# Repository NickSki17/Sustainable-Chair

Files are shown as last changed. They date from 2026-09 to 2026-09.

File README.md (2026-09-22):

# Interlocking Sustainable Foam-Core Chair

A full-scale chair developed around foam-core structural design, interlocking assembly, and laser-cut fabrication. The project includes concept selection, Autodesk Inventor CAD, preliminary FEA, fabrication, and a documented static prototype demonstration.

**Tools:** Autodesk Inventor, Inventor FEA, laser cutting, foam-core fabrication

## Objective and requirements

The design objective was to create a lightweight chair that satisfied the documented dimensional and manufacturing constraints while targeting a 103 kg static-load requirement.

| Requirement | Documented value |
| :--- | :--- |
| Material | 5 mm foam-core sheets |
| Sheet envelope | 457 x 610 mm |
| Target mass | Below 800 g; preferred stretch target below 400 g |
| Assembly | Interlocking slots and tabs; no external fasteners, adhesives, or tape |
| Seat height | 480-530 mm |
| Seat envelope | 410-450 mm wide and deep |
| Backrest height | 280-480 mm |
| Static load requirement | 103 kg |

The engineering report gives a **462 g CAD-predicted mass** calculated from Inventor geometry and material density. This is not a documented physical scale measurement.

## Concept development and selection

Three structural concepts were compared using a Pugh matrix across nine weighted criteria: dimensions, mass, comfort, fabrication, design effort, part count, fastening requirements, appearance, and probability of success. The multi-rib interlocking concept was selected for detailed design.

## Mechanical design and analysis

The selected design uses multi-rib foam-core construction with interlocking slot-and-tab joints. Lines-of-force analysis was used to consider load paths and likely stress-concentration regions before detailed modeling.

The [design-choice and FEA document](Sustainable%20Chair%20Design%20Choice%20and%20FEA.pdf) and [engineering report](Sustainable_Chair_Report.pdf) contain the available analysis documentation, including Autodesk Inventor FEA figures for seat and backrest loading conditions. The original FEA study files and result database are not included.

## Fabrication and physical test

The documented workflow included generating flat-pattern geometry from the CAD design, laser cutting 5 mm foam-core stock, and assembling the parts with press-fit joints without glue or mechanical fasteners.

The available [before-test documentation](Chair%20Before%20Test.pdf) and [after-test documentation](Chair%20After%20Test.pdf) show the physical prototype test evidence. The project documents a static demonstration in which the prototype supported a 103 kg load with minimal observed local damage afterward. This is a physical observation from the documented demonstration, not a load-cell measurement, structural certification, or durability test.

## Sustainability considerations and limitations

The design explores material-conscious choices through low-mass geometry, flat-pattern fabrication, reduced part count, and an interlocking assembly that avoids adhesives and external fasteners. These are design considerations, not a quantified lifecycle or environmental assessment.

The repository does not include carbon-footprint, embodied-energy, cost, lifecycle, or quantified waste-reduction calculations. It also does not include a documented physical mass measurement or durability study.

## Repository structure

```text
Sustainable-Chair/
|-- README.md
|-- .gitignore
|-- Chair After Test.pdf
|-- Chair Before Test.pdf
|-- Sustainable Chair Design Choice and FEA.pdf
|-- Sustainable Chair Ideas.pdf
|-- Sustainable_Chair_Report.pdf
`-- CAD/
    |-- sustainable_chair_assembly.iam
    |-- sustainable_chair_presentation.ipn
    `-- Parts/
        |-- backrest.ipt
        |-- inside_leg.ipt
        |-- inside_leg_2.ipt
        |-- outside_leg.ipt
        |-- seat.ipt
        |-- slats.ipt
        |-- slats_back_over.ipt
        |-- slats_back_under.ipt
        `-- slats_under.ipt
```

## Project files

- [Assembly](CAD/sustainable_chair_assembly.iam)
- [Presentation](CAD/sustainable_chair_presentation.ipn)
- [Parts directory](CAD/Parts/)
- [Engineering report](Sustainable_Chair_Report.pdf)
- [Design choice and FEA document](Sustainable%20Chair%20Design%20Choice%20and%20FEA.pdf)
- [Ideas and concept-development document](Sustainable%20Chair%20Ideas.pdf)
- [Before-test documentation](Chair%20Before%20Test.pdf)
- [After-test documentation](Chair%20After%20Test.pdf)

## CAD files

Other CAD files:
CAD/Parts/backrest.ipt
CAD/Parts/inside_leg.ipt
CAD/Parts/inside_leg_2.ipt
CAD/Parts/outside_leg.ipt
CAD/Parts/seat.ipt
CAD/Parts/slats.ipt
CAD/Parts/slats_back_over.ipt
CAD/Parts/slats_back_under.ipt
CAD/Parts/slats_under.ipt
CAD/sustainable_chair_assembly.iam
CAD/sustainable_chair_presentation.ipn

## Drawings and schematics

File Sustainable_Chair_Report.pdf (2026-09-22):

# Interlocking Sustainable Foam-Core Chair

Nicholas Skiba
Illinois Institute of Technology Chicago, IL
nskiba@hawk.illinoistech.edu

Abstract—A sustainable foam-core chair was designed, analyzed, and tested to meet dimensional and weight requirements while supporting a 103 kg load without fasteners. The goal was to demonstrate lightweight structural design using foam-core to enable low-waste prototyping during the development process. Foam-core, though not recyclable, enables quick and resourceefficient prototyping that exposes structural and ergonomic issues early, guiding more sustainable manufacturing. Reducing waste is essential as it lowers material consumption, decreases environmental impact, and improves the overall efficiency of the design cycle. Three concept designs were made and evaluated using a Pugh chart, and the winning concept was modeled in Inventor. Analysis was done using lines of force sketches along with FEA to find and remove stress concentration. The final CAD model properties predicted 462 g as the weight of the physical chair. A physical prototype was made using a laser cutter and assembled using interlocking parts. The chair was tested incrementally, using lighter to heavier people sitting on the assembled chair, ending with the 103 kg person, where minimal damage occurred. The results demonstrated that careful loadbearing design, light weighting, and targeted reinforcement can produce a sustainable foam-core chair suitable for real-world use.

I. INTRODUCTION
A. Motivation and Context
Sustainable product design reduces material waste and simplifies end-of-life recycling, providing both environmental and economic benefits. Furniture is a common consumer product, and sustainable design approaches can be beneficial. Normally, furniture, especially chairs, is made of wood or plastic which is joined by fasteners, all of which increase price, waste, and make it hard to dispose of. This report explores a design of a lightweight chair made of foam core board, without the use of adhesives or fasteners. Eliminating adhesives and fasteners reduces waste and simplifies end-of-life recycling, making it a relevant case study in sustainable product development. In order to reduce products detrimental environmental impacts, it is important to consider new ways of making products more sustainable.
The design (Fig. 1) demonstrates light weighting principles commonly used in mechanical and aerospace industries, demonstrating how the engineering process can be beneficial for product design. This concept chair is a lightweight, recyclable chair that maintains strength and function. To explore these concepts in practice, this project applies sustainable design principles to develop a sustainable foam-core chair.
B. Project Objectives and Functional Requirements
The primary objective of the project was to design and fabricate a foam-core chair capable of supporting a 103 kg load while meeting dimensional and sustainability criteria. Other functional requirements include:
- Seat height: 480 mm to 530 mm
- Seat depth: 410 mm to 450 mm
- Seat width: 410 mm to 450 mm
- Back height (from seat): 280 mm to 480 mm
- Material: foam core board sheets (457 mm × 610 mm × 5 mm).
- No fasteners, adhesives, or tape.
- Target mass < 800 g, with preference toward < 400 g.

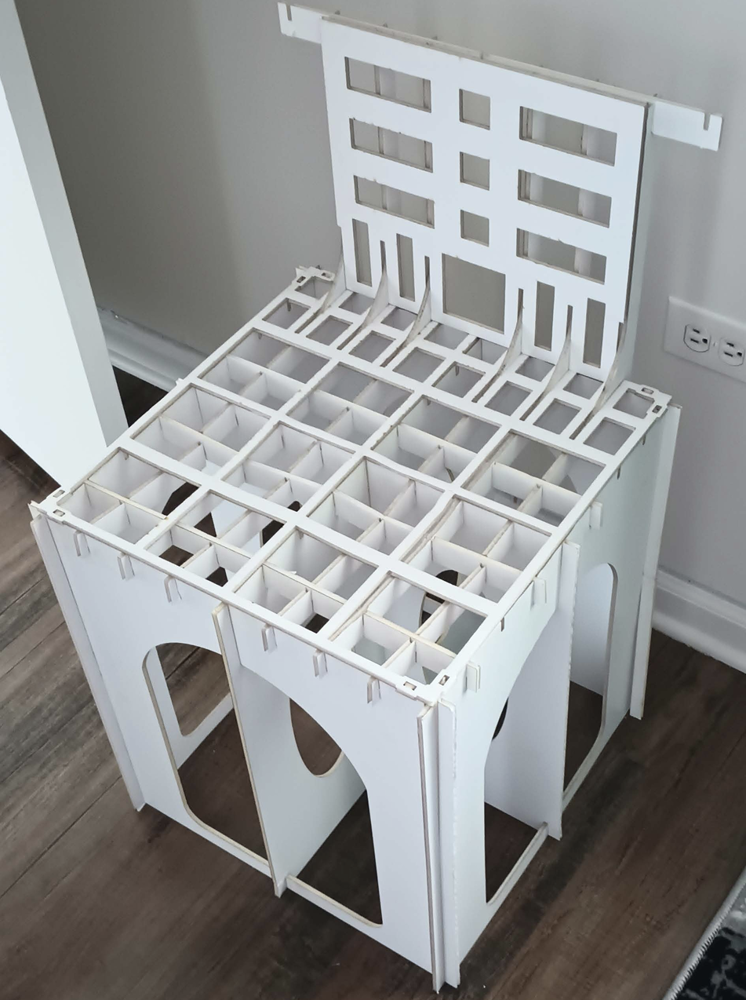
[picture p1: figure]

Fig. 1: Final Prototype

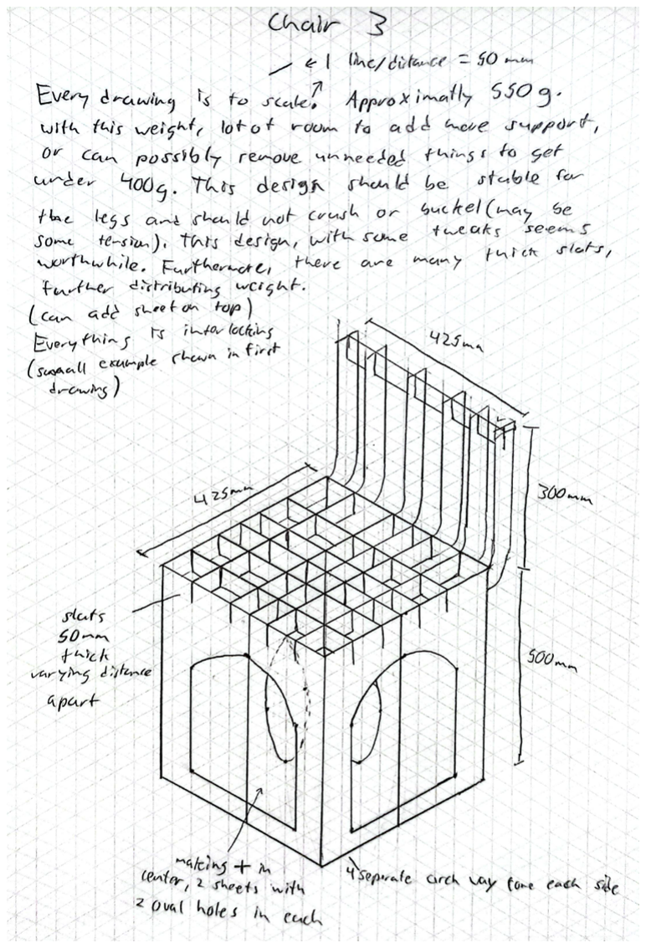
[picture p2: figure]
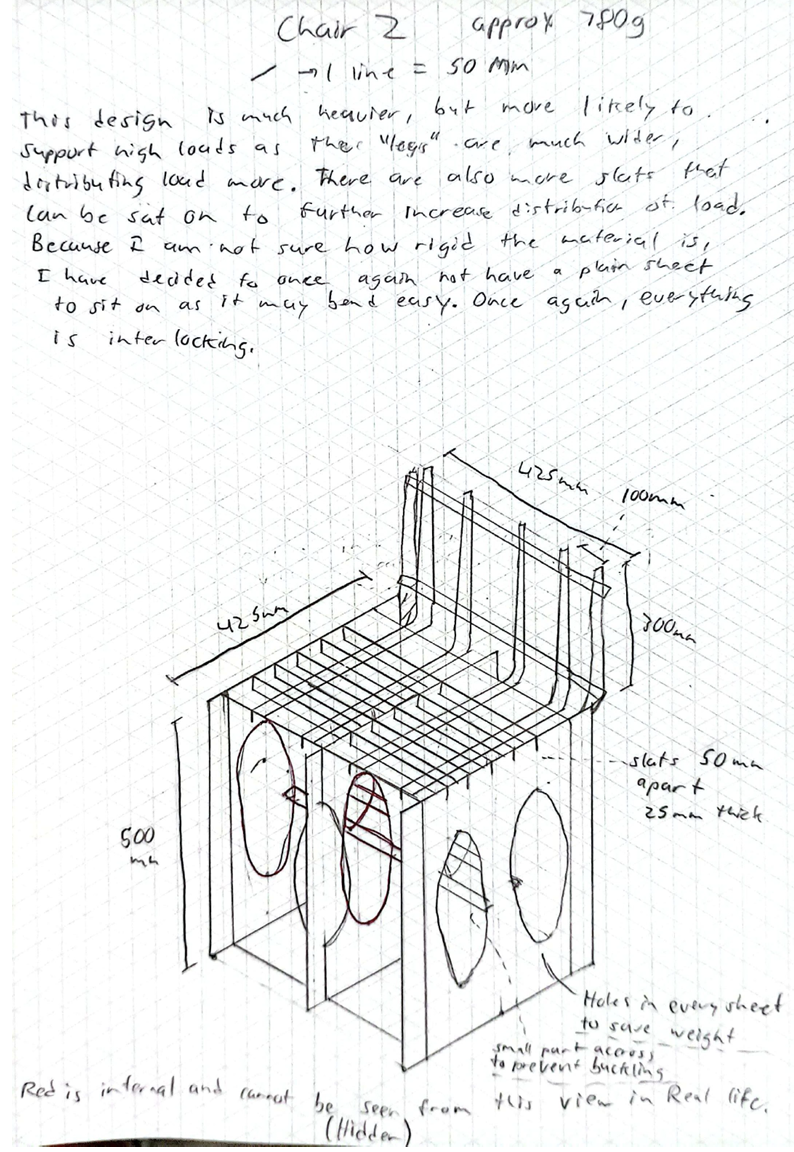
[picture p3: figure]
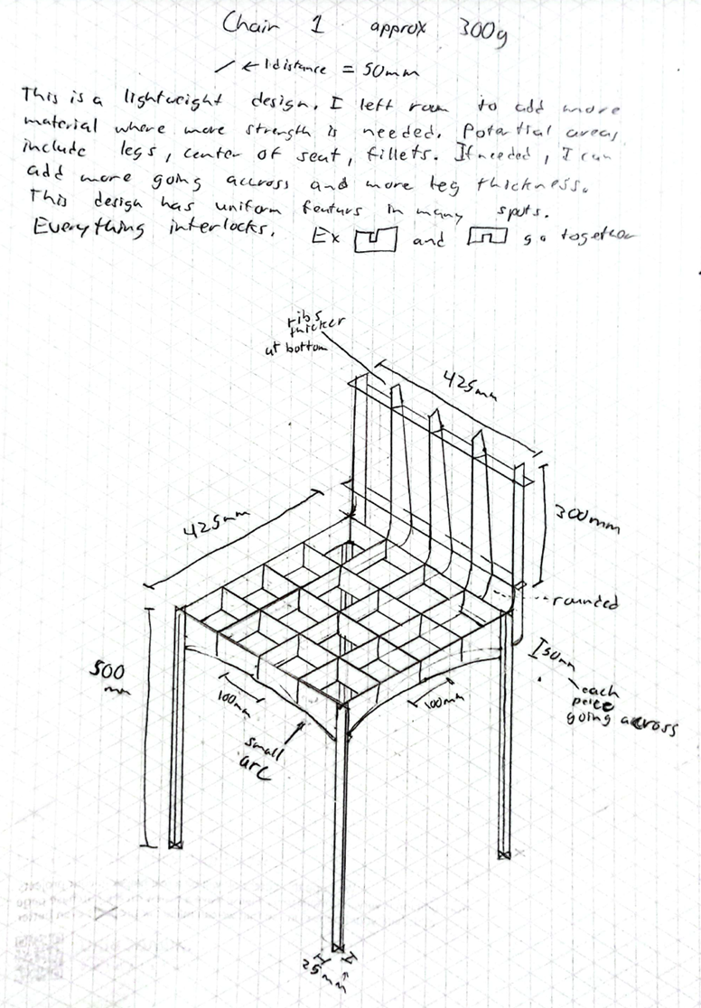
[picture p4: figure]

(a) Design 1 | (b) Design 2 | (c) Design 3

Fig. 2: Hand-Sketched Concepts

II. CONCEPT GENERATION AND EVALUATION

A. Sketches and Concept Descriptions
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

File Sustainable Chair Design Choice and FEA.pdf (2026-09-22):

Sustainable Chair

Nicholas Skiba

September 2025

Criteria | Weight | Baseline | Design 1 | Design 2 | Design 3
Dimensions | 4 | 0 | 0 | 0 | 0
Chair Weight | 4 | 0 | + | 0 | 0
Looks | 1 | 0 | 0 | 0 | 0
Comfort | 1 | 0 | - | 0 | +
Ease of Build | 2 | 0 | + | - | 0
Ease of Design | 2 | 0 | + | - | 0
Number of Parts | 3 | 0 | 0 | 0 | 0
Fasteners | 4 | 0 | 0 | 0 | 0
Chance of Success | 6 | 0 | - | + | +
Total (raw) | | 0 | 1 | −1 | 2
Weighted Total | | 0 | 1 | 2 | 7

Table 1: Chair Pugh Chart

Best Design: Design 3

This is my Pugh chart. There are many different criteria, from functionality, requirements, ease of fabrication, and looks and comfort. I choose requirements such as dimensions, weight, and fasteners to have the second highest weight(4) because it matters because it is a requirement for the project; otherwise, I can lose points. I choose the chance of success to be the highest weight as if it does not work, then the project will have failed. I choose things like ease of build and design and number of parts to have some weight as it makes fabrication time greater or less, which does not matter for the grade, however, it should not take forever to do as there are due dates. Finally, I choose the looks and comfort to have the least weight, as they really do not matter much. With these criteria and weights, I found that my third design is the best option, so I will continue with it and start CAD modeling.

FEA Images

1

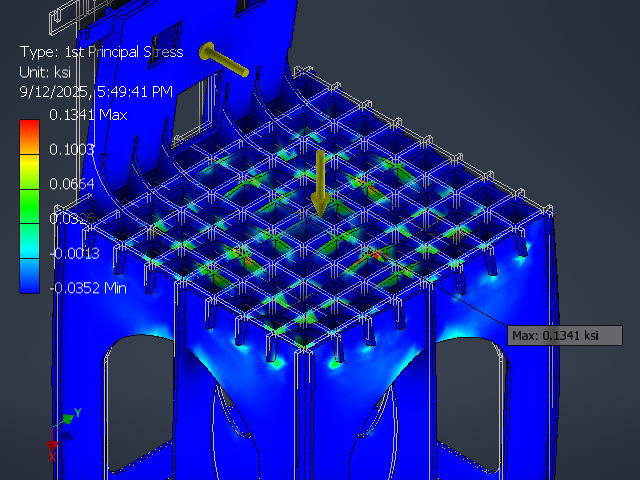
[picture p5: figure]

Figure 1: Stress Analysis of All Weight On Seat of Chair

2

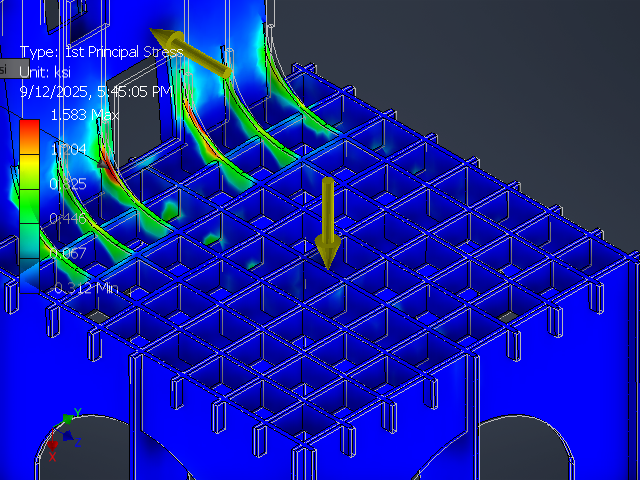
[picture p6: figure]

Figure 2: Stress Analysis of Half Weight On Back of Chair

Properties

3

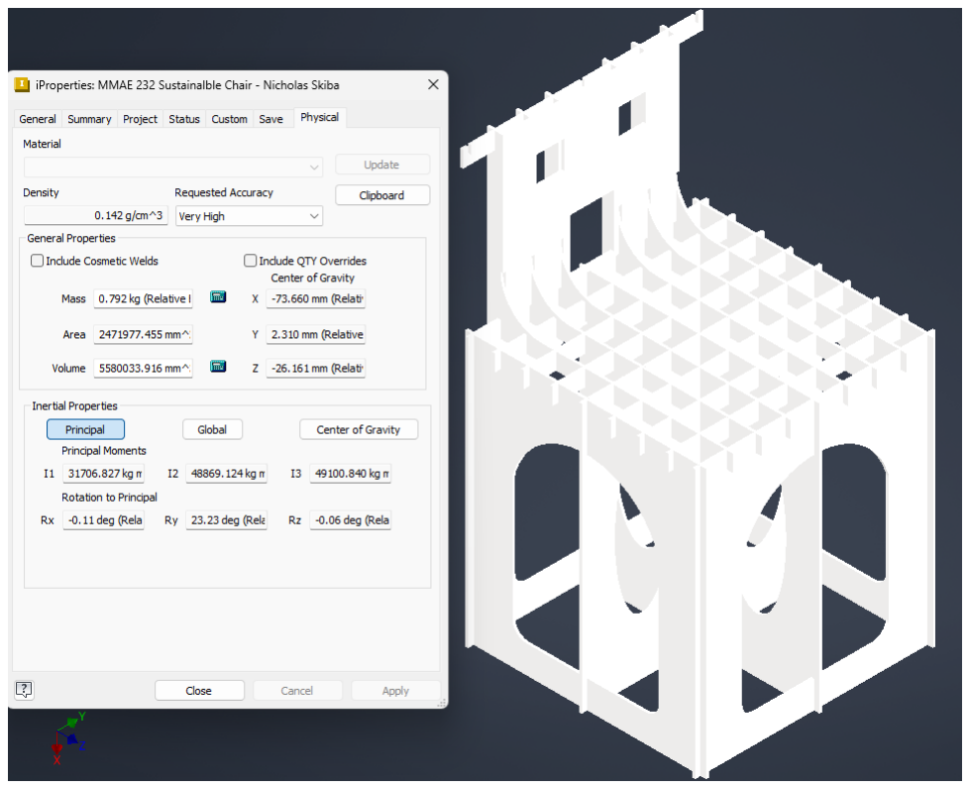
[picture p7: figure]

Figure 3: Properties(Correct Density of Material So Mass is Correct (792g)

4

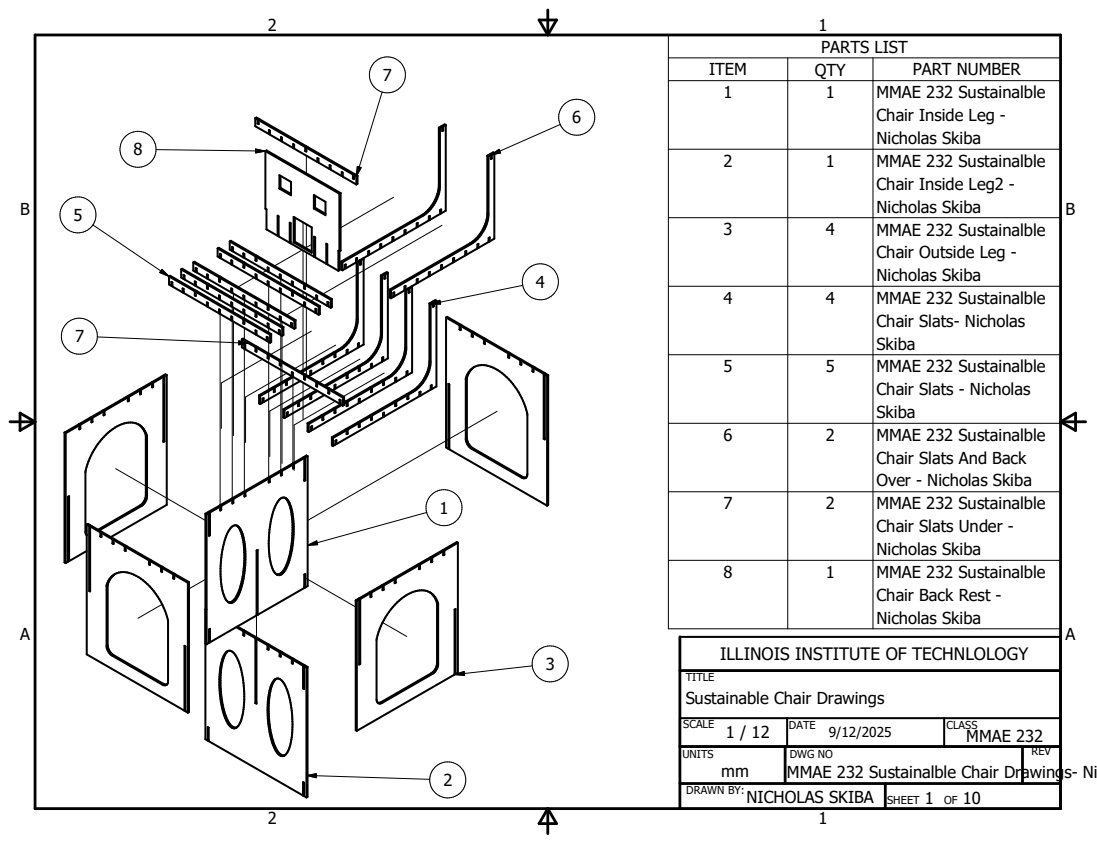
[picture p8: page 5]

PARTS LIST

ITEM | QTY | PART NUMBER
1 1 | | MMAE 232 Sustainalble Chair Inside Leg -Nicholas Skiba

2 1 | | MMAE 232 Sustainalble Chair Inside Leg2 -Nicholas Skiba

3 4 | | MMAE 232 Sustainalble Chair Outside Leg -Nicholas Skiba

4 4 | | MMAE 232 Sustainalble Chair Slats- Nicholas Skiba

5 5 | | MMAE 232 Sustainalble Chair Slats - Nicholas Skiba

6 2 | | MMAE 232 Sustainalble Chair Slats And Back Over - Nicholas Skiba

7 2 | | MMAE 232 Sustainalble Chair Slats Under -Nicholas Skiba

8 1 | | MMAE 232 Sustainalble Chair Back Rest -Nicholas Skiba

ILLINOIS INSTITUTE OF TECHNLOLOGY

TITLE
Sustainable Chair Drawings

SCALE 1 / 12 | DATE 9/12/2025 | CLASS MMAE 232

UNITS mm | DWG NO | REV

MMAE 232 Sustainalble Chair Drawings- Ni

SHEET 1 OF 10 DRAWN BY:NICHOLAS SKIBA

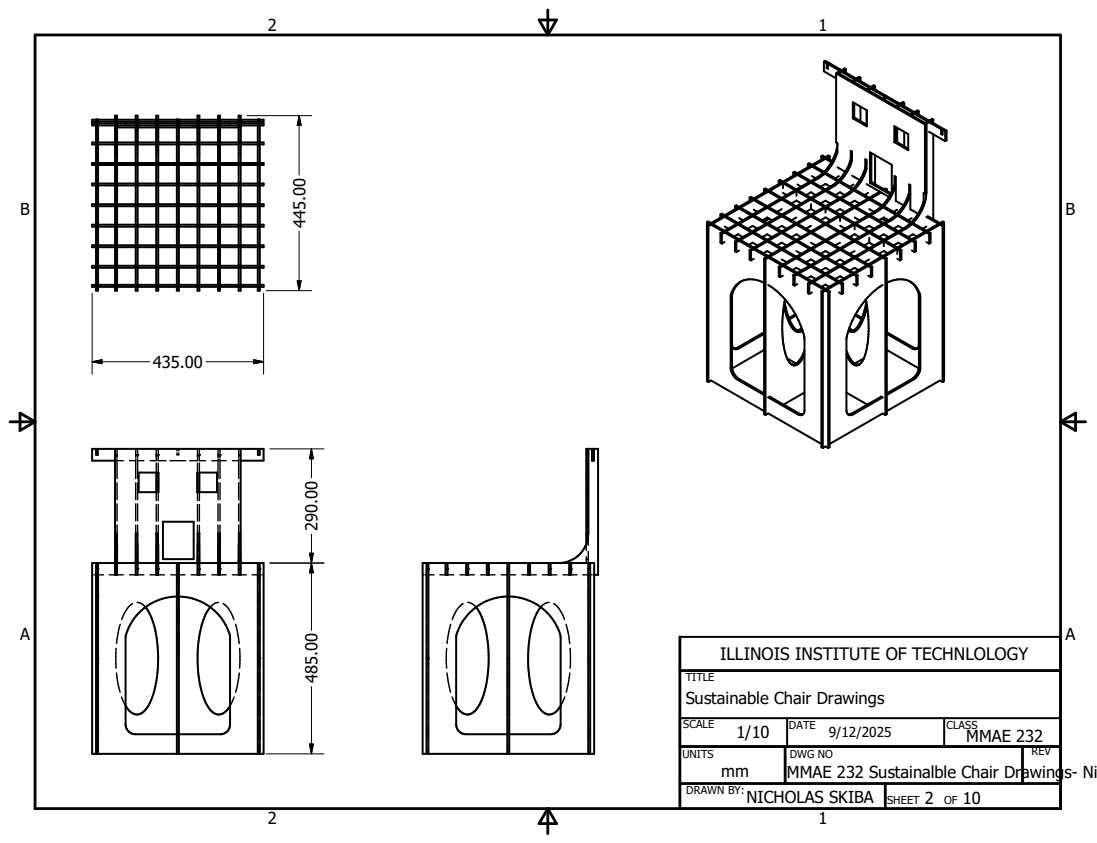
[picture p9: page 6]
mm ⁴⁸⁵.00 290.00

ILLINOIS INSTITUTE OF TECHNLOLOGY

TITLE
Sustainable Chair Drawings

SCALE 1/10 | DATE 9/12/2025 | CLASS MMAE 232

UNITS | DWG NO | REV

MMAE 232 Sustainalble Chair Drawings- Ni

SHEET 2 OF 10 DRAWN BY:NICHOLAS SKIBA

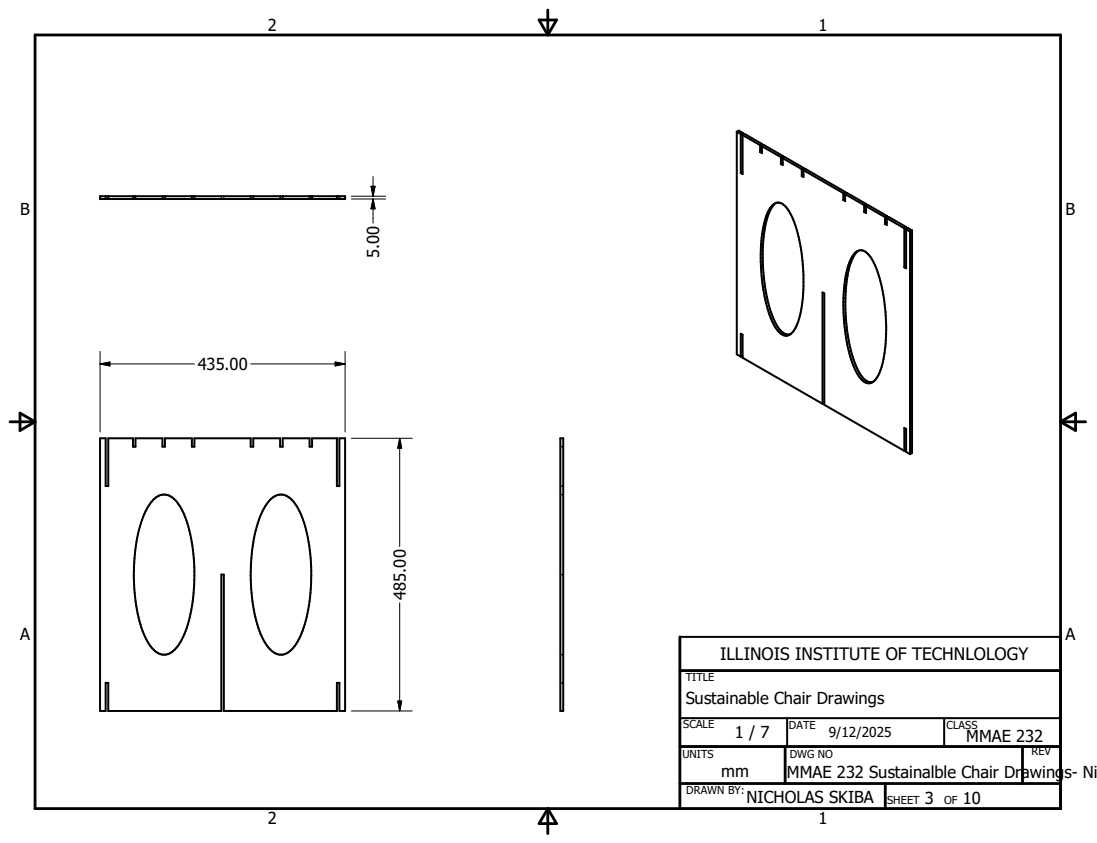
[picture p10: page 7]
mm ⁴⁸⁵.00

ILLINOIS INSTITUTE OF TECHNLOLOGY

TITLE
Sustainable Chair Drawings

SCALE 1 / 7 | DATE 9/12/2025 | CLASS MMAE 232

UNITS | DWG NO | REV

MMAE 232 Sustainalble Chair Drawings- Ni

SHEET 3 OF 10 DRAWN BY:NICHOLAS SKIBA

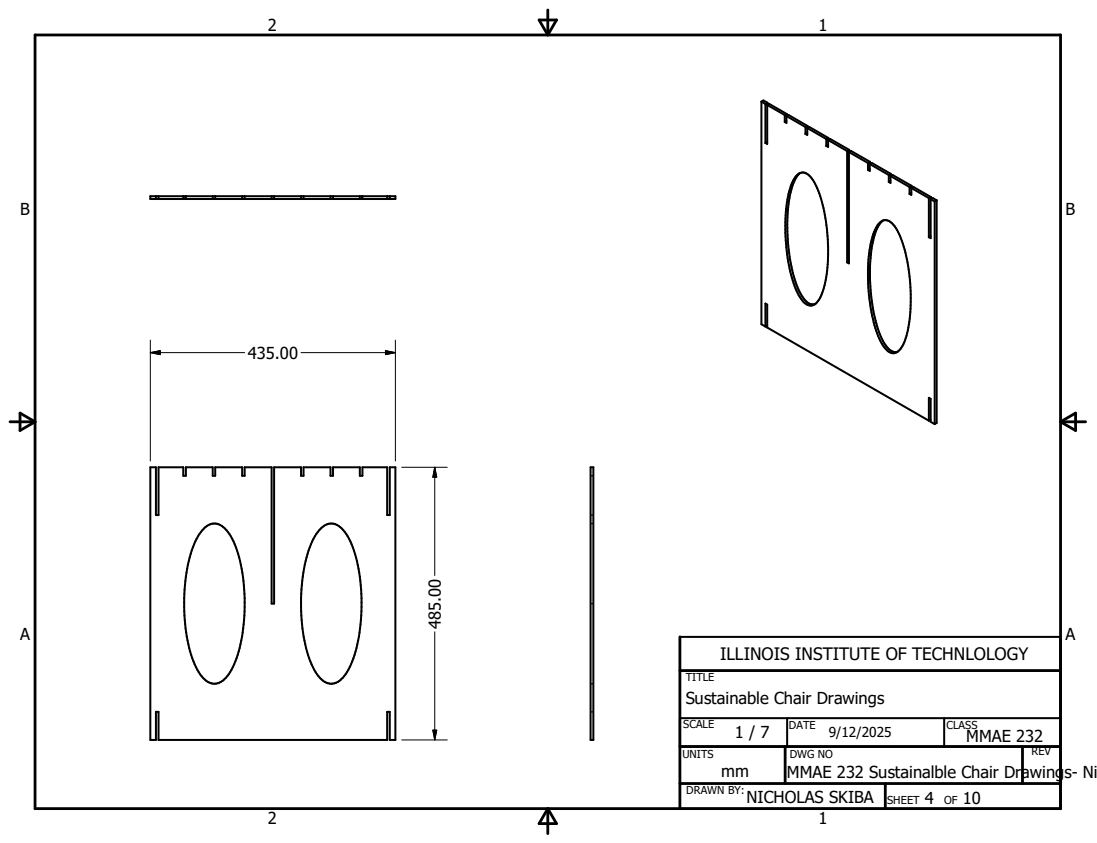
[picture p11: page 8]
mm ⁴⁸⁵.00

ILLINOIS INSTITUTE OF TECHNLOLOGY

TITLE
Sustainable Chair Drawings

SCALE 1 / 7 | DATE 9/12/2025 | CLASS MMAE 232

UNITS | DWG NO | REV

MMAE 232 Sustainalble Chair Drawings- Ni

SHEET 4 OF 10 DRAWN BY:NICHOLAS SKIBA

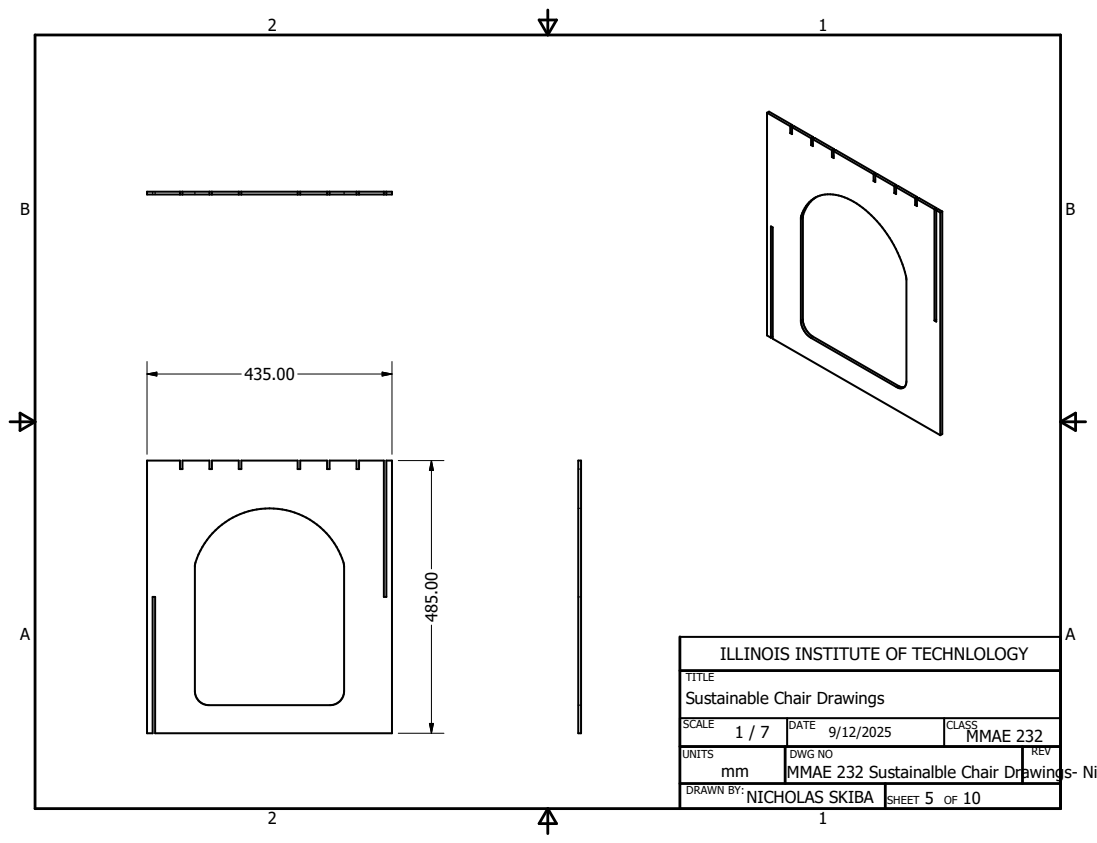
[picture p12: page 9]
mm ⁴⁸⁵.00

ILLINOIS INSTITUTE OF TECHNLOLOGY

TITLE
Sustainable Chair Drawings

SCALE 1 / 7 | DATE 9/12/2025 | CLASS MMAE 232

UNITS | DWG NO | REV

MMAE 232 Sustainalble Chair Drawings- Ni

SHEET 5 OF 10 DRAWN BY:NICHOLAS SKIBA


ILLINOIS INSTITUTE OF TECHNLOLOGY

TITLE
Sustainable Chair Drawings

SCALE 1 / 4 | DATE 9/12/2025 | CLASS MMAE 232

UNITS mm | DWG NO | REV

MMAE 232 Sustainalble Chair Drawings- Ni

SHEET 6 OF 10 DRAWN BY:NICHOLAS SKIBA


ILLINOIS INSTITUTE OF TECHNLOLOGY

TITLE
Sustainable Chair Drawings

SCALE 1 / 6 | DATE 9/12/2025 | CLASS MMAE 232

UNITS mm | DWG NO | REV

MMAE 232 Sustainalble Chair Drawings- Ni

SHEET 7 OF 10 DRAWN BY:NICHOLAS SKIBA

mm ³²⁰.00

ILLINOIS INSTITUTE OF TECHNLOLOGY

TITLE
Sustainable Chair Drawings

SCALE 1 / 6 | DATE 9/12/2025 | CLASS MMAE 232

UNITS | DWG NO | REV

MMAE 232 Sustainalble Chair Drawings- Ni

SHEET 8 OF 10 DRAWN BY:NICHOLAS SKIBA


ILLINOIS INSTITUTE OF TECHNLOLOGY

TITLE
Sustainable Chair Drawings

SCALE 1 / 4 | DATE 9/12/2025 | CLASS MMAE 232

UNITS mm | DWG NO | REV

MMAE 232 Sustainalble Chair Drawings- Ni
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
